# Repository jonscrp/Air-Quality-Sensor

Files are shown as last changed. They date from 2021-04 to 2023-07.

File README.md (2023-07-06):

<details>
<summary> Air Quality Sensor V4 using WiFi to Google Sheets 🌱 </summary>

 Welcome to our ASRC Community Sensor Lab! We're still building this space but feel free to use the materials available. Contact [kkrueger@gc.cuny.edu](mailto:kkrueger@gc.cuny.edu) if you have any questions. We'll try to answer as soon as possible!
 
 The Air Quaity Sensor (AQS) is a **low-cost**, **low-power** DIY device with sensors for **CO2**, **temp-pressure-relativehumidity**, and **PM2.5** (dust or smoke). It has an on-board logger and WiFi connectivity to Google Sheets for (almost) real time data reporting. 
<br>

V3 has code for the SPS30 PM2.5 and HSC differential pressure (Met Museum) sensors. If these are not present the code keeps going and reports 'no sensor' to SD log and google sheet. Additionally, keeps the start-stop for Wifi and sleeps all for ~25mA operation. Version 4 coming soon.

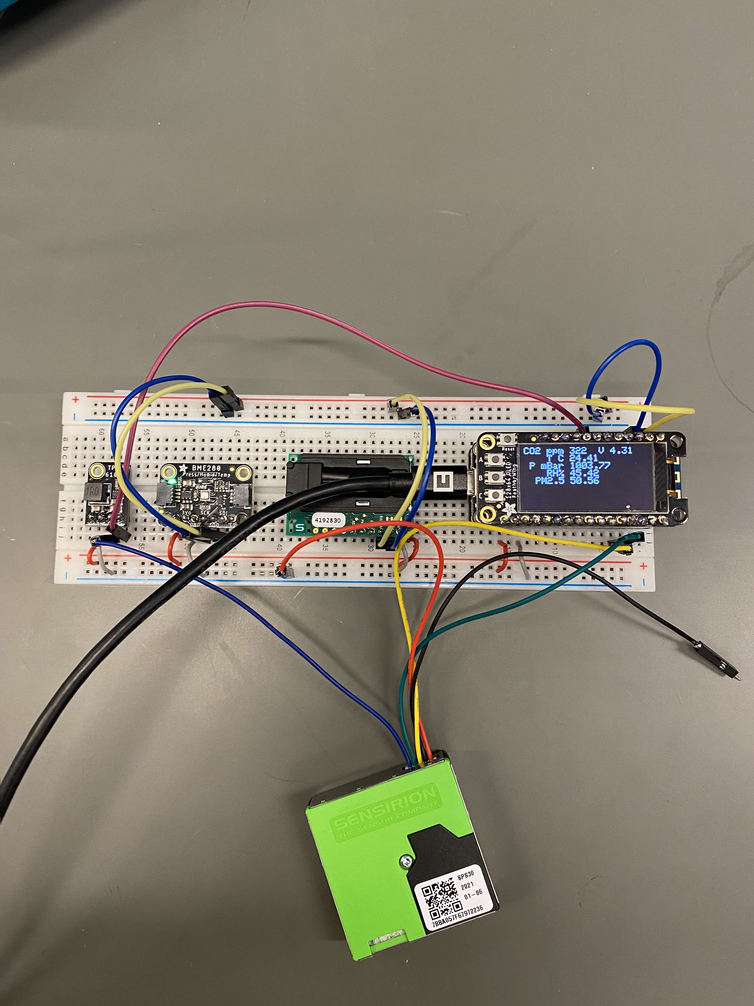
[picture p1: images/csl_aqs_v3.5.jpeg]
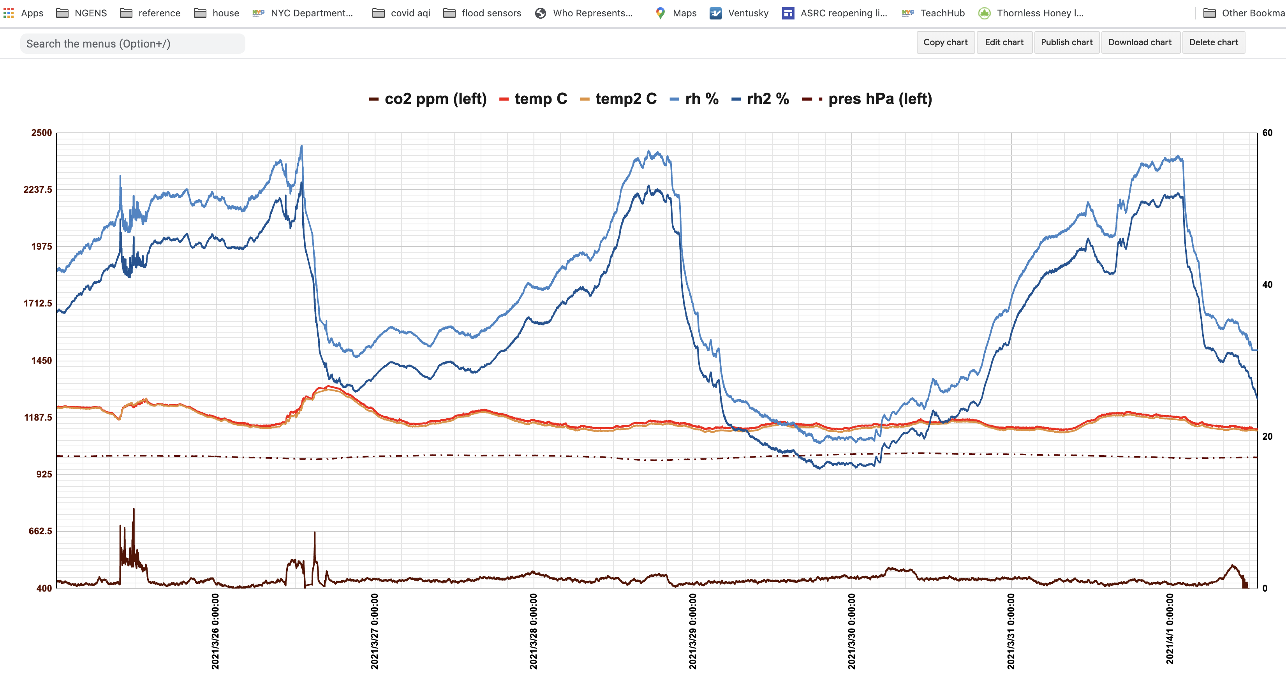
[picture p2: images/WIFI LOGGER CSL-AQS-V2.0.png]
  
<br>
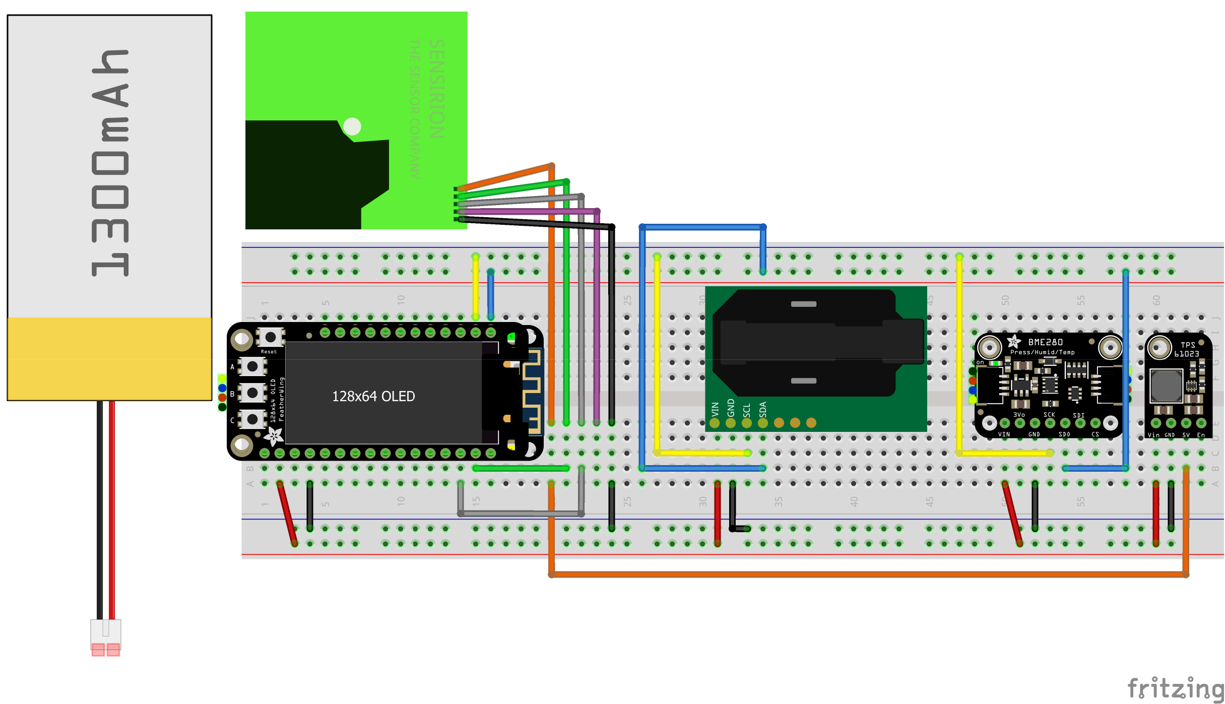
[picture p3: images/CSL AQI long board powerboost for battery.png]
                  
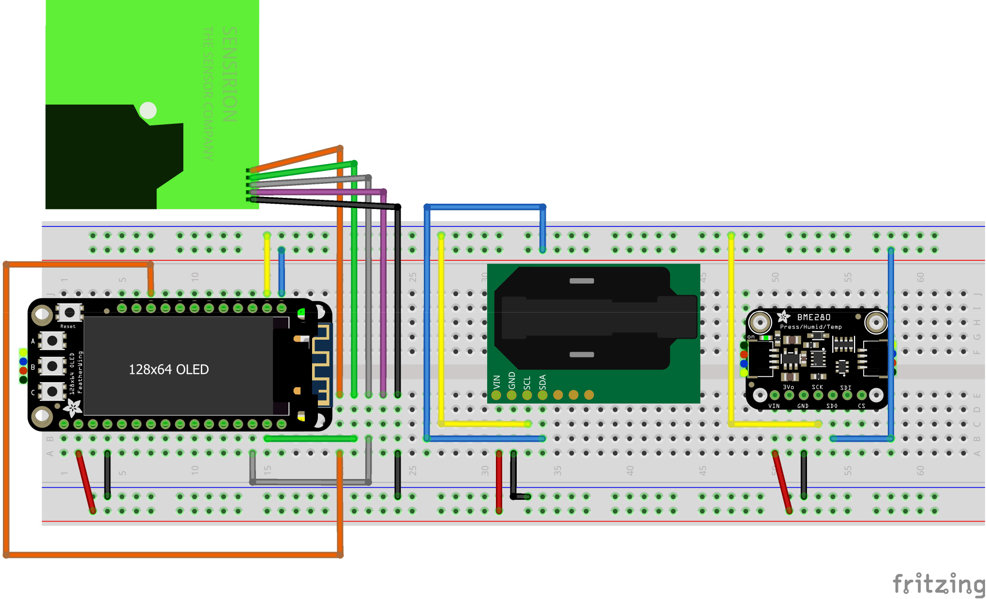
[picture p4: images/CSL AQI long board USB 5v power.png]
                  

<br>

## Contents:

   * Community Sensor Lab 🌱 - Air Quality Sensor
      * [Starting From Scratch](#Starting-From-Scratch)
      * [Assembly](#Assembly)
      * [Arduino IDE](#Arduino-IDE)
      * [Setting Up Google Spreadsheet](#Setting-Up-Google-Spreadsheet)

## Starting-From-Scratch💡 
  #### [List of Parts](#Parts-List-)

### Soldering
[Guide On How To Solder Air Quality Sensor](https://docs.google.com/document/d/1l6jeO-1NOw7vDZXchC9iGBB8vkmnokzwbz_wixmtFyU/edit?usp=sharing)

## Assembly 
* [Air Quality Sensor Boards Assembly](https://docs.google.com/document/d/1AezJ0XiPEsc3vEHGtJqxCqGEe5GDv0d0T-DoVZDCgCY/edit?usp=sharing)

* [How to Connect Sensors to Boards](https://docs.google.com/document/d/1BrGlBl2Zau5XgyUAorEzxkr_Fa7h0j_XQgn0lQ-tBvw/edit?usp=sharing)

## Arduino-IDE
* [Installing Arduino and Getting Started](https://docs.google.com/document/d/16o8Np3GaZfSjQlxNWIgi12ycb2CosCJ2blwEGiTplbA/edit?usp=sharing)
### Downloading Code From Github 🐈‍⬛  
If you are new to Github, **Welcome!** 
Check out our guide:
[Downloading CSL AQS Code from Github](https://docs.google.com/document/d/1Vb9AufqkUwsVKtdozXMc4aboDjLqBNuyTXmZpECdKx0/edit?usp=sharing)

## Setting-Up-Google-Spreadsheet
### HTTP-Request-to-Google-Spreadsheet 🌐
The Air Quality Sensor can post data in (almost) real-time to a spreadsheet online through HTTP methods!
For instructions on getting the AQS connected with a Google Spreadsheet, take a look at our guide: [HTTP Posting to Google Spreadsheet](https://docs.google.com/document/d/1yNolfJr7s9rs_ewV7vN-bUsllEiPPxo2xeQbsmszQKE/edit?usp=sharing).
<br>In our guide we provide:
* A template specifically for the Air Quality Sensor 
* Step-by-step instructions to using the Google Script Editor for the AQS and deploying your app script
* Managing troubleshooting issues
* Step-by-step instructions to then connecting your App Script to the AQS through the Arduino IDE

## Parts-List 🖥 
Here are the materials you will need with links of where to find them. 

### FeatherM0-Microcontroller-Boards

| Board | Board Image | Use | Link |
|---|---|---|:---:|
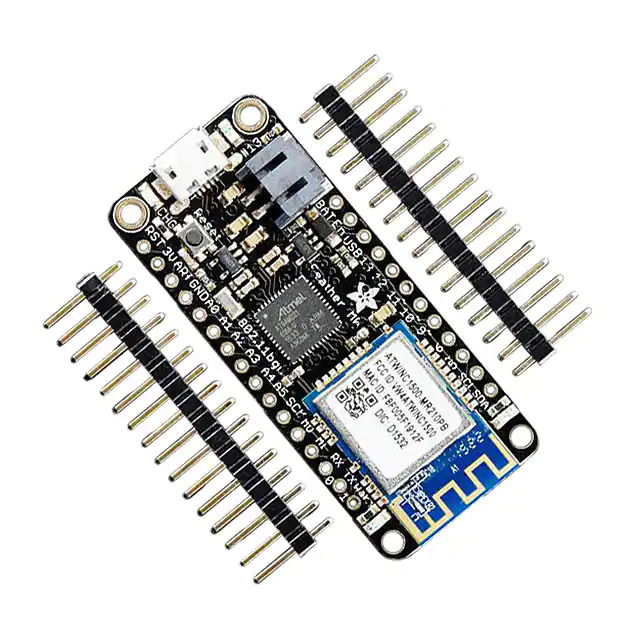
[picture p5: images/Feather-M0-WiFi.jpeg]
|Feather M0 WiFi (WINC1500))|   |Connects to WiFi network. Brain of the system|[Adafruit](https://www.adafruit.com/product/3010)
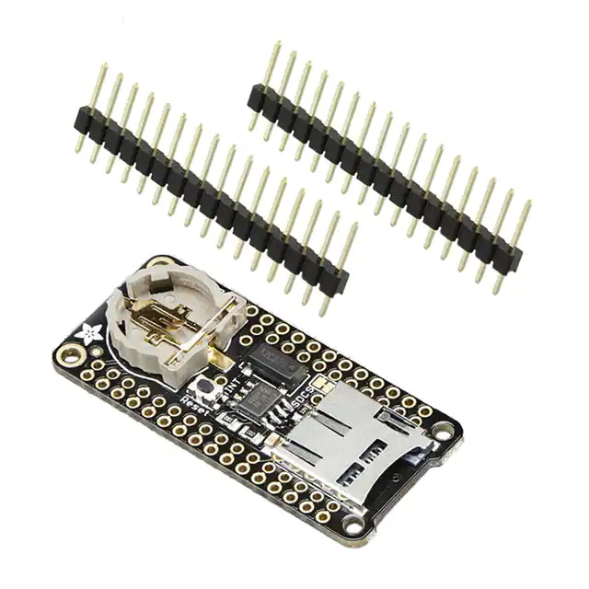
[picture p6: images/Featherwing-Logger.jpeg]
|Featherwing Logger (RTC microSD)|  |Slot for microSD. Has a real time clock|[Adafruit](https://www.adafruit.com/product/2922)
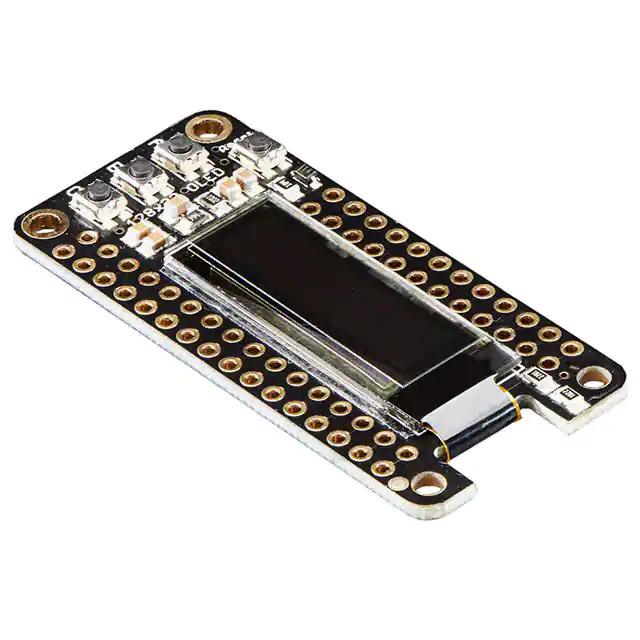
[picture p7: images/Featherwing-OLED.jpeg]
|Featherwing OLED  | |Displays data values and can graph functions|[Adafruit](https://www.adafruit.com/product/4650)
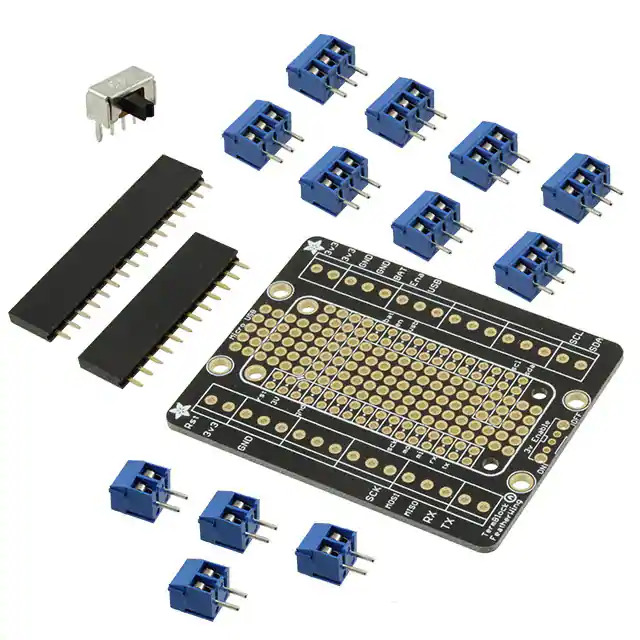
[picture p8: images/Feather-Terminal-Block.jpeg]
|Feather Terminal Block | |Holds all the components together|[Adafruit](https://www.adafruit.com/product/2926)

### Sensors
| Sensor | Sensor Image | Use | Purchase Link |
|---|---|---|:---:|
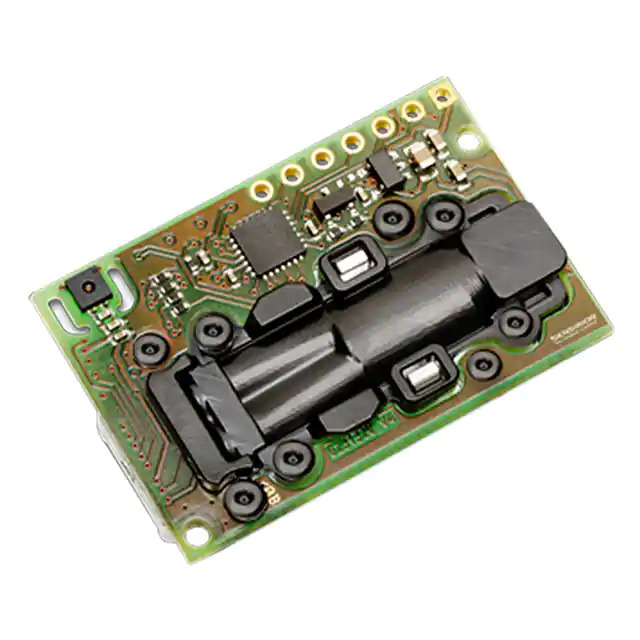
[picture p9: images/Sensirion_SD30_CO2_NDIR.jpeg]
|Sensirion SD30 CO2 NDIR| |Measures CO2 in PPM|[Digi-Key](https://www.digikey.com/en/products/detail/sensirion-ag/SCD30/8445334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)
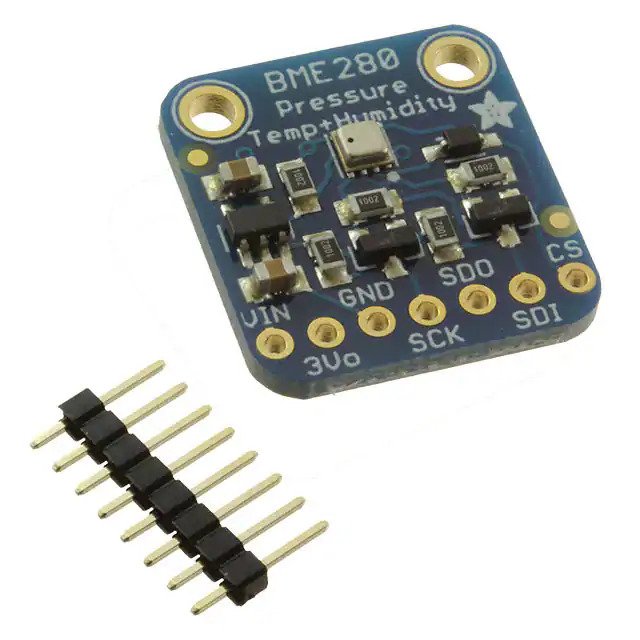
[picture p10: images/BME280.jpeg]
|BME280 Temp. Press. Rel Humidity|  | Measures temperature C, pressure hPa and relative humidity %|[Digi-Key](https://www.digikey.com/en/products/detail/adafruit-industries-llc/2652/5604372)
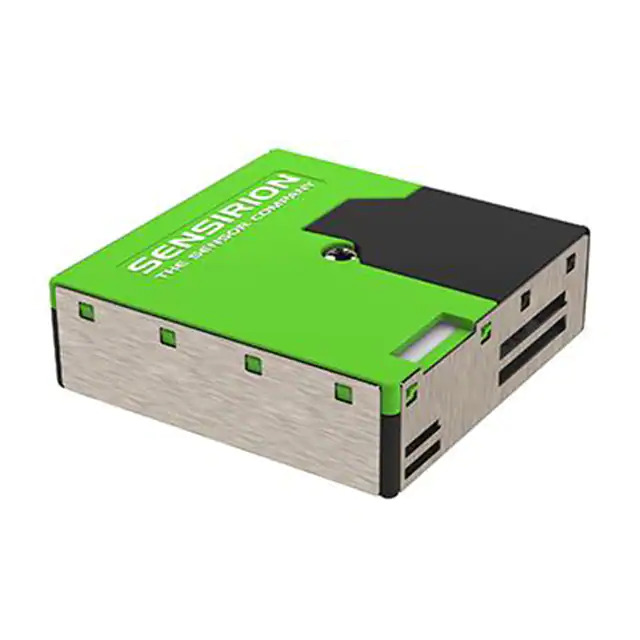
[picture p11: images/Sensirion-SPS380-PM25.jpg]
|Sensirion SPS380 PM2.5| |Measures particulate matter PM2.5+|[Digi-Key](https://www.digikey.com/en/products/detail/sensirion-ag/SPS30/9598990)
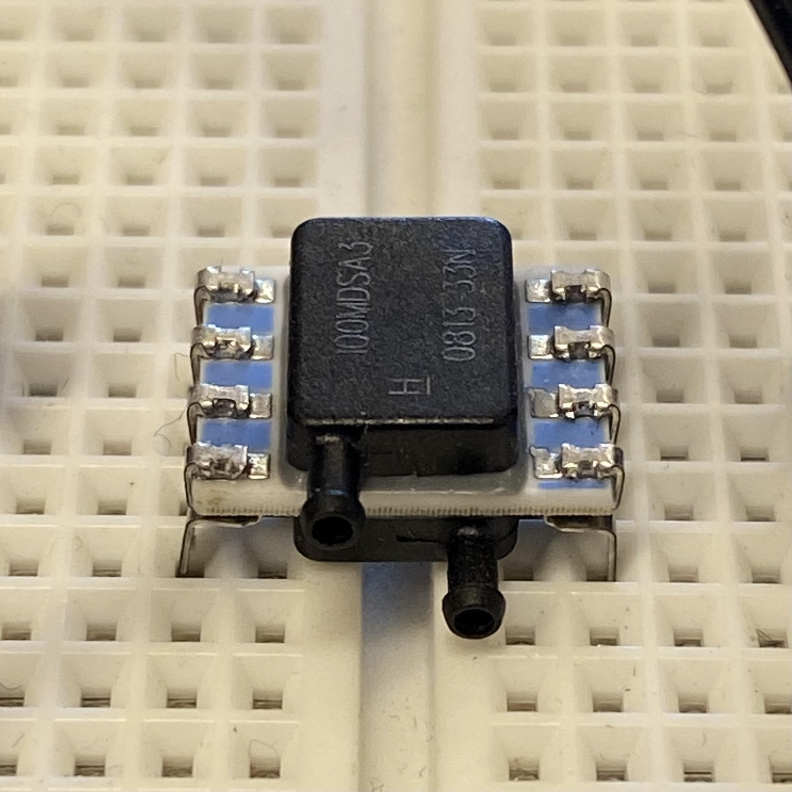
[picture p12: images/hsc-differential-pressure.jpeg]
|Differential Pressure| |Measures particulate matter PM2.5+|[No Link Available at this time](https://www.digikey.com/en/products/detail/sensirion-ag/SPS30/9598990)

### Additional-Parts
| Part | Part Image | Use | Purchase Link |
|---|---|---|:---:|
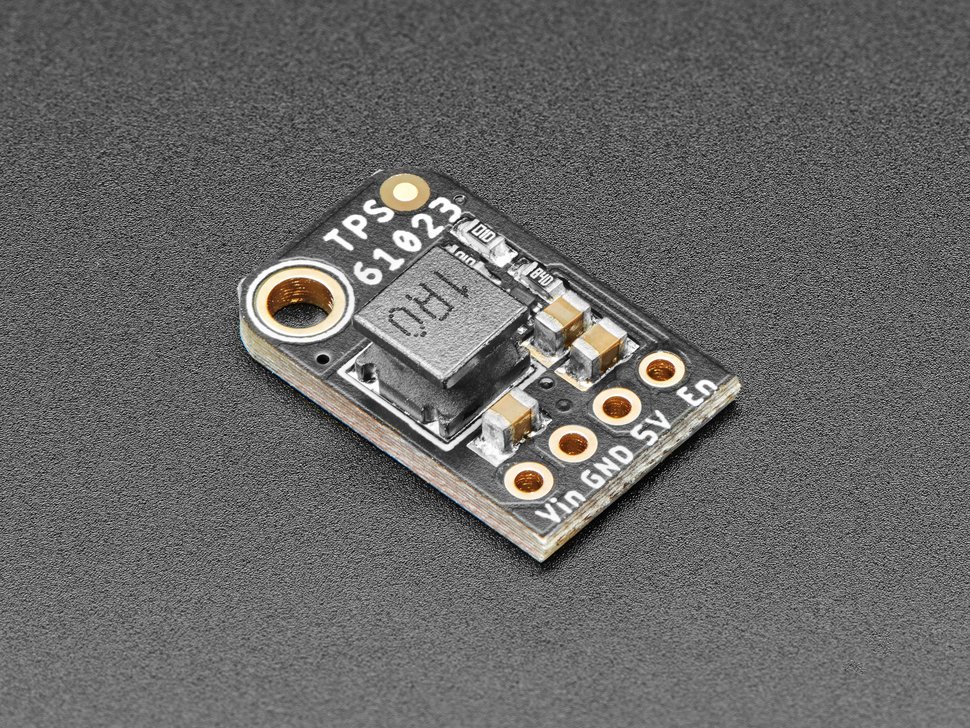
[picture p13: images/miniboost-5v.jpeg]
|MiniBoost 5V|  |Boosts battery pawer to 5V|[Digi-Key](https://www.adafruit.com/product/4654)
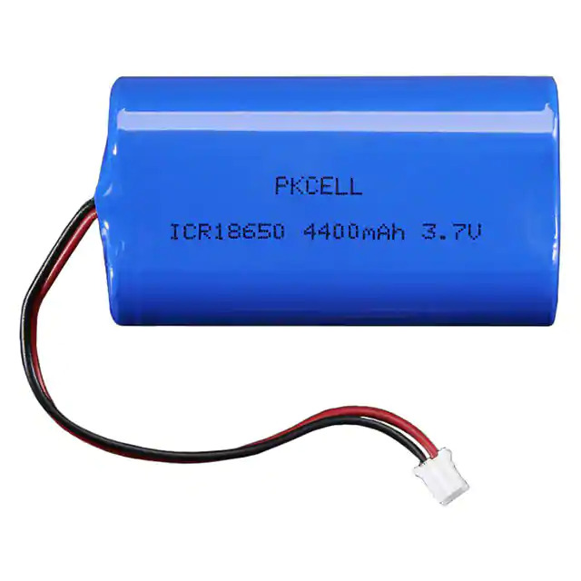
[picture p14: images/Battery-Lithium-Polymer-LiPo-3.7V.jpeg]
|Battery Lithium Polymer LiPo 3.7V|  |Device's battery|[Digi-Key](https://www.digikey.com/en/products/detail/adafruit-industries-llc/354/5054541)
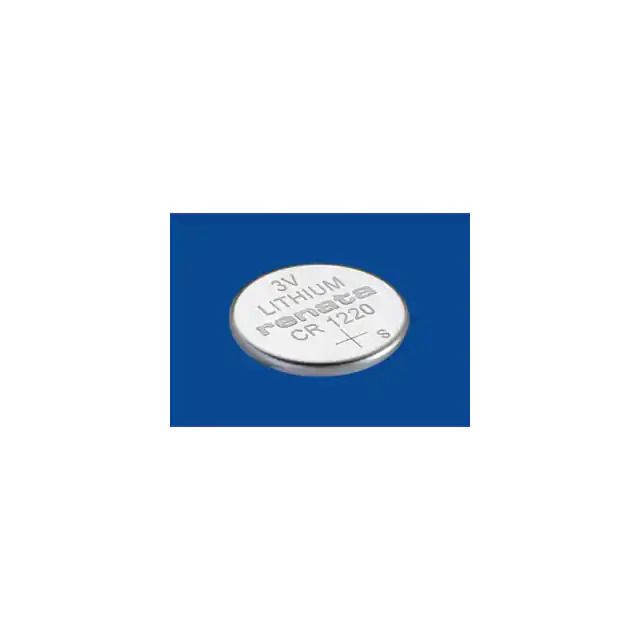
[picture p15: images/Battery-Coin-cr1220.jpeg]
|Battery Coin cr1220|  |Clock Battery|[Digi_Key](https://www.digikey.com/en/products/detail/renata-batteries/RENATA-CR1220-TS-1/13283109)
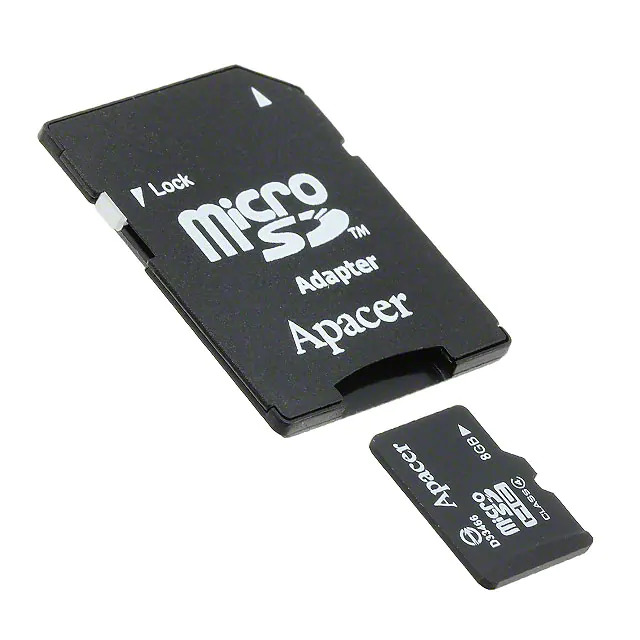
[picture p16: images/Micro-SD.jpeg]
|Micro SD| |non volatile memory|[Digi-Key](https://www.digikey.com/en/products/detail/delkin-devices-inc/USDCOEM-16GB/13882332)
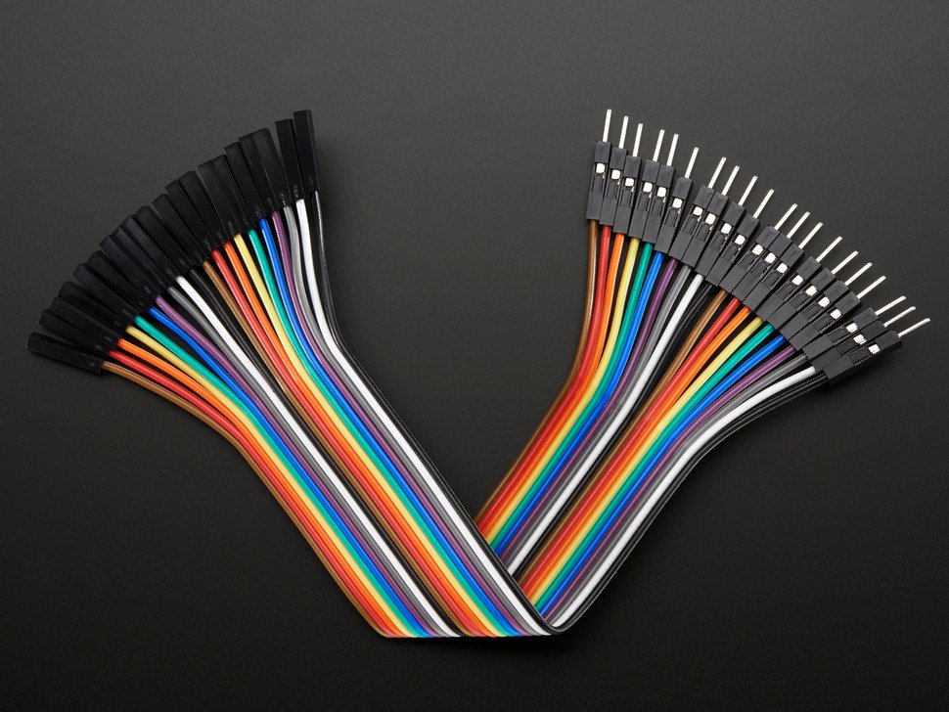
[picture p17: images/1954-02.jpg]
|Jumper Wires| |connecting|[Adafruit](https://www.adafruit.com/product/1954)

### Diagram 🔦          
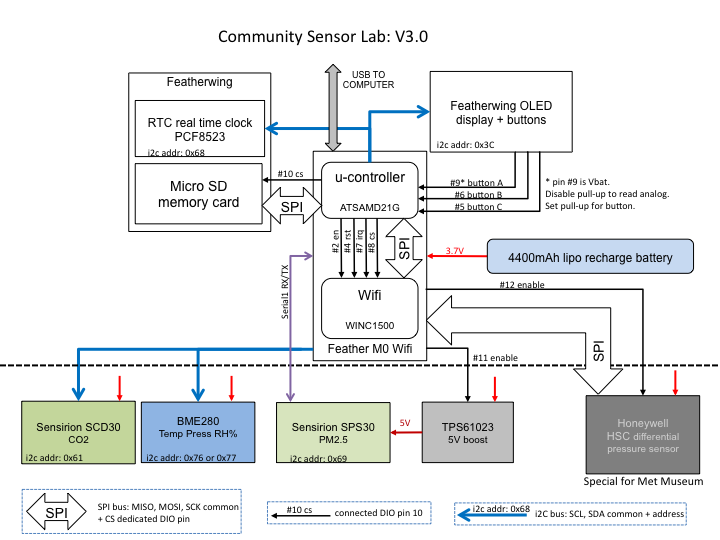
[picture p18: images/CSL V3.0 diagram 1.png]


### Solar Integration ☀️ 
The Air Quality Sensor can be powered by the sun!
For instructions on getting the AQS connected to a solar panel visit our document guide: [Solar Integration for the AQS](https://docs.google.com/document/d/1Q-aV4gpCV_NFu_VYhCmv1KPlE8r25asAGBMgROmjtNk/edit?usp=sharing).

## Versions 🛠
### Air-Quality-Sensor-V4
This is currently still being worked upon. The code has been updated to allow communication from the google sheet to the sensor and allow provisioning so that the Wifi information does not need to be inputted into the code beforehand allowing it to be more versatile.[Upcoming-Version-4.0](https://github.com/Community-Sensor-Lab/Air-Quality-Sensor/tree/CSL-AQS-V4.0)
### Air-Quality-Sensor-V3
This is our current utilized version of code for our Air Quality Sensor. The code on this page is the latest code that is stable for usage. Bigger display screen, power booster, PM 2.5 and differential pressure sensors are included in this version [Version-3.0](https://github.com/Community-Sensor-Lab/Air-Quality-Sensor/tree/CSL-AQS-V3.0)
### Air-Quality-Sensor-V2.1
Code from version 2.1 of the Air Quality Sensor can be seen on the branch [Version-2.1](https://github.com/Community-Sensor-Lab/Air-Quality-Sensor/tree/CSL-AQS-V2.1)
### Air-Quality-Sensor-v1
Code from the first version of the Air Quality Sensor can be seen on the branch [Version-1](https://github.com/Community-Sensor-Lab/Air-Quality-Sensor/tree/Version-1)
</details>

 <details>

   <summary> .ino files </summary>
   
   ```
   CO2_SCD30.ino
   CSL-AQS-V4.ino
  
   ```
 </details>

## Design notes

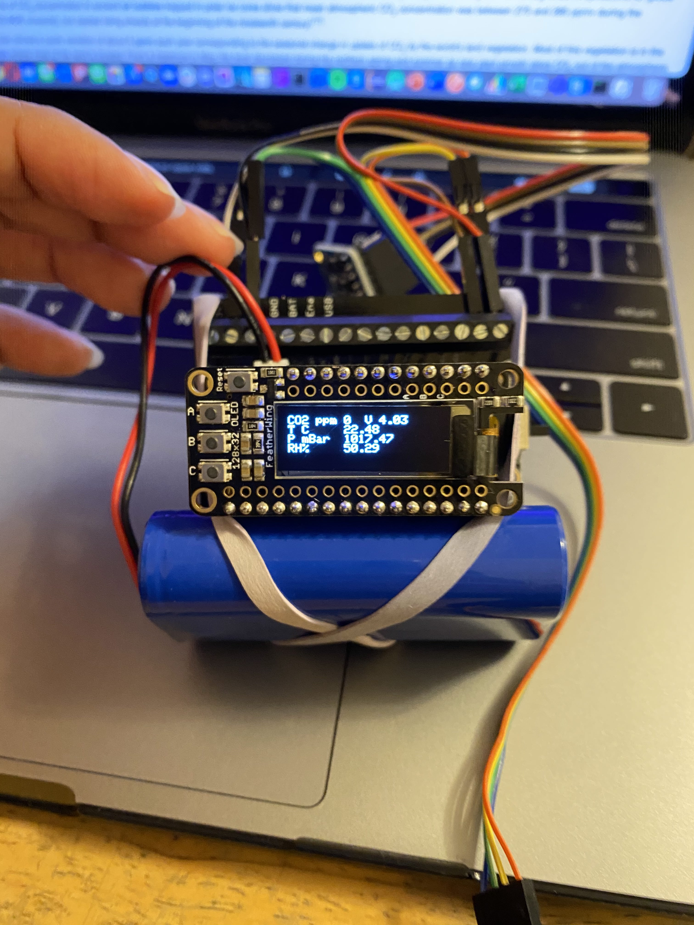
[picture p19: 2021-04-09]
images/air-qaulity-sensor-V2.jpeg

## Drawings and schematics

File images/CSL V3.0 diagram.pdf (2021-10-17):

# Community Sensor Lab: V3.0

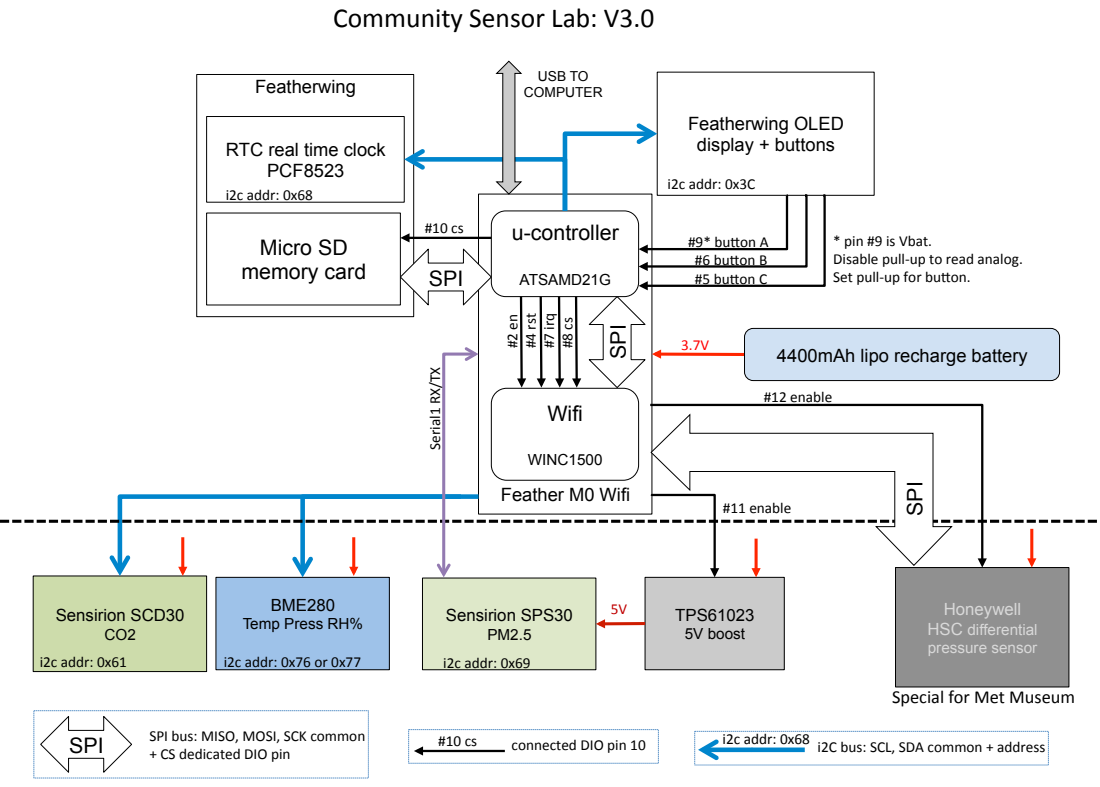
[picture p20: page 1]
Feather M0 Wifi; u-controller; ATSAMD21G; Wifi; WINC1500; SPI; #4 rst; #7 irq #8 cs; Featherwing; Micro SD; memory card; Featherwing OLED display + buttons; i2c addr: 0x3C; Sensirion SCD30 CO2; Sensirion SPS30 PM2.5; i2c addr: 0x61; i2c addr: 0x76 or 0x77; i2c addr: 0x69; Honeywell HSC differential pressure sensor; #11 enable; TPS61023 5V boost; #12 enable; 4400mAh lipo recharge battery; USB TO COMPUTER; Serial1 RX/TX; SPI bus: MISO, MOSI, SCK common; connected DIO pin 10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

RTC real time clock
PCF8523
i2c addr: 0x68

* pin #9 is Vbat.
Disable pull-up to read analog.
Set pull-up for bu<on.

Special for Met Museum SPI

BME280
Temp Press RH%

+ CS dedicated DIO pin

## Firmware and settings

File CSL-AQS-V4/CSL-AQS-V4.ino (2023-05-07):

    
/*
   COMMUNITY SENSOR LAB - AIR QUALITY SENSOR

   featherM0-Wifi + featherwing adalogger-SD-RTC + SCD30-CO2 + BME280-TPRH + OLED display + SPS30-PM2.5

   The SCD30 has a minimum power consumption of 5mA and cannot be stop-started. It's set to 55s (30s nominal)
   sampling period and the featherM0 sleeps for 2 x 16 =32s, wakes and waits for data available.
   Button A toggles display on/off but must be held down for 16s max and then wait 16s to toggle again.

   Logs: date time, co2, t, rh, t2, press, rh2, battery voltage, status

   https://github.com/Community-Sensor-Lab/Air-Quality-Sensor

   Global status is in uint8_t stat in bit order:
   0- 0000 0001 0x01 SD card not present
   1- 0000 0010 0x02 SD could not create file
   2- 0000 0100 0x04 RTC failed
   3- 0000 1000 0x08 SCD30 CO2 sensor not available

   4- 0001 0000 0x10 SCD30 CO2 sensor timeout
   5- 0010 0000 0x20 SPS30 PM2.5 sensor malfunction
   6- 0100 0000 0x40 HSC differential pressure sensor absent or malfunction
   7- 1000 0000 0x80 future: google.com ssl connection error

   RICARDO TOLEDO-CROW NGENS, ESI, ASRC, CUNY,
   AMALIA TORRES, CUNY, July 2021

*/
#include <SPI.h>
#include <SD.h>
#include <Wire.h>
#include <Adafruit_SleepyDog.h>
#include "RTClib.h"
#include "SparkFun_SCD30_Arduino_Library.h"
#include <Adafruit_GFX.h>
#include <Adafruit_SH110X.h>  // oled library
#include <Adafruit_Sensor.h>
#include <Adafruit_BME280.h>
#include <SensirionI2CSen5x.h>
#include <WiFi101.h>
#include <HoneywellTruStabilitySPI.h> // for differential pressure sensor for Met https://github.com/huilab/HoneywellTruStabilitySPI.git
#include "arduino_secrets.h" // wifi name and password in .h file. see tab


#define VBATPIN A7  // this is also D9 button A disable pullup to read analog
#define BUTTON_A  9 // Oled button also A7 enable pullup to read button
#define BUTTON_B  6 // oled button
#define BUTTON_C  5 // oled button
#define SD_CS 10    // Chip select for SD card default for Adalogger
#define HSC_CS 12   // Chip select for Honeywell HSC diff press sensor
#define MAXBUF_REQUIREMENT 48

#if (defined(I2C_BUFFER_LENGTH) &&                 \
     (I2C_BUFFER_LENGTH >= MAXBUF_REQUIREMENT)) || \
    (defined(BUFFER_LENGTH) && BUFFER_LENGTH >= MAXBUF_REQUIREMENT)
#define USE_PRODUCT_INFO
#endif


char server[] = "script.google.com"; // name address for Google scripts as we are communicationg with the scripg (using DNS)
// these are the commands to be sent to the google script: namely add a row to last in Sheet1 with the values TBD
String payload_base =  "{\"command\":\"appendRow\",\"sheet_name\":\"Sheet1\",\"values\":";
String payload = "";
char header[] = "DateTime, CO2, Tco2, RHco2, Tbme, Pbme, RHbme, vbat(mV), status, mP1.0, mP2.5, mP4.0, mP10, ncP0.5, ncP1.0, ncP2.5, ncP4.0, ncP10, avgPartSize, Thsc, dPhsc";
int status = WL_IDLE_STATUS;
String ssidg, passcodeg, gsidg;
uint16_t CO2; // for oled display
float Pmv = 0;
float Nox = 0;
float Voc = 0;

SensirionI2CSen5x sen5x;
WiFiSSLClient client; // make SSL client
RTC_PCF8523 rtc; // Real Time Clock for RevB Adafruit logger shield
Adafruit_SH1107 display = Adafruit_SH1107(64, 128, &Wire); // large OLED display
Adafruit_BME280 bme; // the bme tprh sensor
File logfile;  // the logging file
SCD30 CO2sensor; // sensirion SCD30 CO2 NDIR
TruStabilityPressureSensor diffPresSens(HSC_CS, -100.0, 100.0 ); // HSC differential pressure sensor for Met Eric Breunitg
uint8_t stat = 0; // status byte

void setup(void) {
  pinMode(VBATPIN, INPUT);
  pinMode(LED_BUILTIN, OUTPUT);
  digitalWrite(LED_BUILTIN, LOW);

  Serial.begin(9600);
  delay(5000);
  Serial.println(__FILE__);
  WiFi.setPins(8, 7, 4, 2);  

  initializeOLED();
  initializeSen5x(); // PM sensor
  initializeSCD30(25); // CO2 sensor to 30s more stable (1 min max recommended)
  initializeBME();      // TPRH
  initializeHSC();
  logfile = initializeSD(); // SD card and RTC
  AP_getInfo(ssidg, passcodeg, gsidg); 
  //initializeWiFi();
}

char outstr[160];
int32_t Tsleep = 0;
bool displayState = true;
bool buttonAstate = true;
int lastTimeToggle = 0;
int timeDebounce = 100;

void loop(void)  {

  uint8_t ctr = 0;
  stat = stat & 0xEF; // clear bit 4 for CO2 sensor

  String bmeString = readBME(); // get data string from BME280 "T, P, RH, "
  String bme = readBME();
 
  // parsing out the t p rh float values
  float Tbme = bme.toFloat();
  bme = bme.substring(bme.indexOf(", ") + 2);
  float Pbme = bme.toFloat();
  bme = bme.substring(bme.indexOf(", ") + 2);
  float RHbme = bme.toFloat();


  String sen5xString = readSen5x();
  String sen5x = readBME();

  String co2String = readSCD30(Pbme);

  DateTime now;
  now = rtc.now(); // fetch the date + time

  pinMode(VBATPIN, INPUT); // read battery voltage
  float measuredvbat = analogRead(VBATPIN) * 0.006445;
  pinMode(BUTTON_A, INPUT_PULLUP);

  delay(5000); // wait for the sps30 to stabilize
  String hscString = readHSC(); // read the differential pressure sensor HSC

  //  sprintf(outstr, "%02u/%02u/%02u %02u:%02u:%02u, %.2d, %.2f, %.2f, %.2f, %.2f, %.2f, %.2f, %x, ",
  //          now.year(), now.month(), now.day(), now.hour(), now.minute(), now.second(),
  //          CO2, Tco2, RHco2, Tbme, Pbme, RHbme, measuredvbat, stat);

  sprintf(outstr, "%02u/%02u/%02u %02u:%02u:%02u, ", now.year(), now.month(), now.day(), now.hour(), now.minute(), now.second());

  payloadUpload(String(outstr) + co2String + bmeString + String(measuredvbat) + String(", ") + String(stat) + String(", ") + sen5xString + hscString);

  Serial.println(header);
  Serial.println(String(outstr) + co2String + bmeString + String(measuredvbat) + String(", ") + String(stat) + String(", ") + hscString + sen5xString);

  logfile.println(String(outstr) + co2String + bmeString + String(measuredvbat) + String(", ") + String(stat) + String(", ") + sen5xString + hscString);
  logfile.flush();   // Write to disk. Uses 2048 bytes of I/O to SD card, power and takes time

  // sleep cycle
  for (int i = 1; i <= 8; i++)  {  // 124s = 8x16s sleep, only toggle display
    displayState = toggleButton(BUTTON_A, displayState, buttonAstate, lastTimeToggle, timeDebounce);
    if (displayState)  { // turn display on with data
      display.clearDisplay();
      display.setCursor(0, 0);
      display.print("CO2 ppm "); display.print(CO2);
      display.print("  V "); display.println(measuredvbat);
      display.print("    T C "); display.println(Tbme);
      display.print(" P mBar "); display.println(Pbme);
      display.print("    RH% "); display.println(RHbme);
      display.print("  VOC "); display.println(Voc);
      display.print("  NOX "); display.println(Nox);
      display.print("  NewPM "); display.print(Pmv);
      display.display();
    }
    else  {  // turn display off
      display.clearDisplay();
      display.display();
    };
    //int sleepMS = Watchdog.sleep();// remove comment for low power
    delay(16000); // uncomment to debug because serial communication doesn't come back after sleeping
  }
}

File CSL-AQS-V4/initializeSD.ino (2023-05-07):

/*

*/

File initializeSD()  {
  File logFile;
  if (!SD.begin(SD_CS)) {  // see if the card is present and can be initialized:
    Serial.println("Card failed, or not present.");
    stat = stat | 0x01; // set bit 1 if SD error
  }
  else  {
    Serial.print("starting SD card... ");
    char filename[] = "LOG0000.TXT";  // create a new file//increase 0000
    for (uint16_t i = 0; i <= 9999; i++) {
      filename[3] = i / 1000 + '0';    //48 ascii character value of 0 //integer division by
      filename[4] = i / 100 - 10 * (i / 1000) + '0';
      filename[5] = i / 10 - 10 * (i / 100) + '0'; //integer division 100
      filename[6] = i % 10 + '0';   //modulo 10
      if (!SD.exists(filename)) {  // only open a new file if it doesn't exist
        logFile = SD.open(filename, FILE_WRITE);
        break;  // leave the loop
      }
    }
    if (!logFile) {
      Serial.println("Couldn't create file");
      stat = stat | 0x02;
    }
    else  {
      Serial.print("logging to file: ");
      Serial.println(filename);
      logFile.println(header);
      logFile.flush();
    }
  }

  Serial.print("starting RTC... ");
  Wire.begin();  // connect to RTC
  if (!rtc.begin()) {
    Serial.println("RTC failed");
    stat = stat | 0x04; // 3rd bit set 'rtc not started'
//    display.clearDisplay();
//    display.setCursor(0, 0);
    display.println("RTC Not ]");
    display.display();
  }
  else
    Serial.println("RTC Connected");
    display.println("RTC Connected");
    display.display();
  // TO SET TIME at compile: run once to syncro then run again with line commented out
  //rtc.adjust(DateTime(F(__DATE__), F(__TIME__)));

  return logFile;
}

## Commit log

2021-03-25 Update arduino_secrets.h
    added Hannah's dorm wifi
2021-03-25 Create wifi_logger_proto.gs
    google script to upload data from CSL sensor system to google sheets
2021-04-09 powerpoint with CSL-AQS-V2.0 system
    sytem, pinouts,
2021-04-20 battery and sensor images :)
2021-05-06 fixed all errors with the code
    [initializeWiFi.ino]
2021-07-07 sps30 sensor integration
2021-07-29 Update CSL-AQS-V2.1.ino
    changed scd30 timing to 30s from 1m for more stability but more power consumption
2021-08-05 add difpressure sensor. cleaned up and made so that if no sps30 or scd30 present still works
2021-08-05 Update arduino_secrets.h
    removed secrets
2021-08-11 wrap up of loose ends :w Please enter the commit message for your changes. Lines starting
    [initializeSD.ino, initializeWiFi.ino, payloadUpload.ino]
2022-11-18 added fritzing
    [UPDATED CSL AQI long board.2.fzz]
2023-02-10 removed frtitzing. Added new fritzing w/ battery and one w/o
2023-02-27 updating to most recent display board
2023-05-07 fixed typos and removed old comments
    [CSL-AQS-V4.ino, initializeSD.ino]
